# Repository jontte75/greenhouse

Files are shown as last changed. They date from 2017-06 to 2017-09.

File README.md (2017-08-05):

# Greenhouse Project #

This project contains source and fritzing of a project to automate a small greenhouse. For now, the soil-moisture probe is not "stable" enough, so automatic watering is not yet implemented. The current version does not contain a web-server, but sends data to thingspeak instead.

### Greenhouse repository ###
* source code for arduino microcontroller (first versions for pro mini, and later for mega)
* source code for one chip pic's, like Omega2 
* simplified fritzing picture of project.

### How do I get set up? ###
No special set-ups needed. Connect necessary devices and sensors to a arduino (project uses now Mega 2560 clone, but any other should work just fine, but be aware of memory requirements)

A simplified fritzing pic about the project:
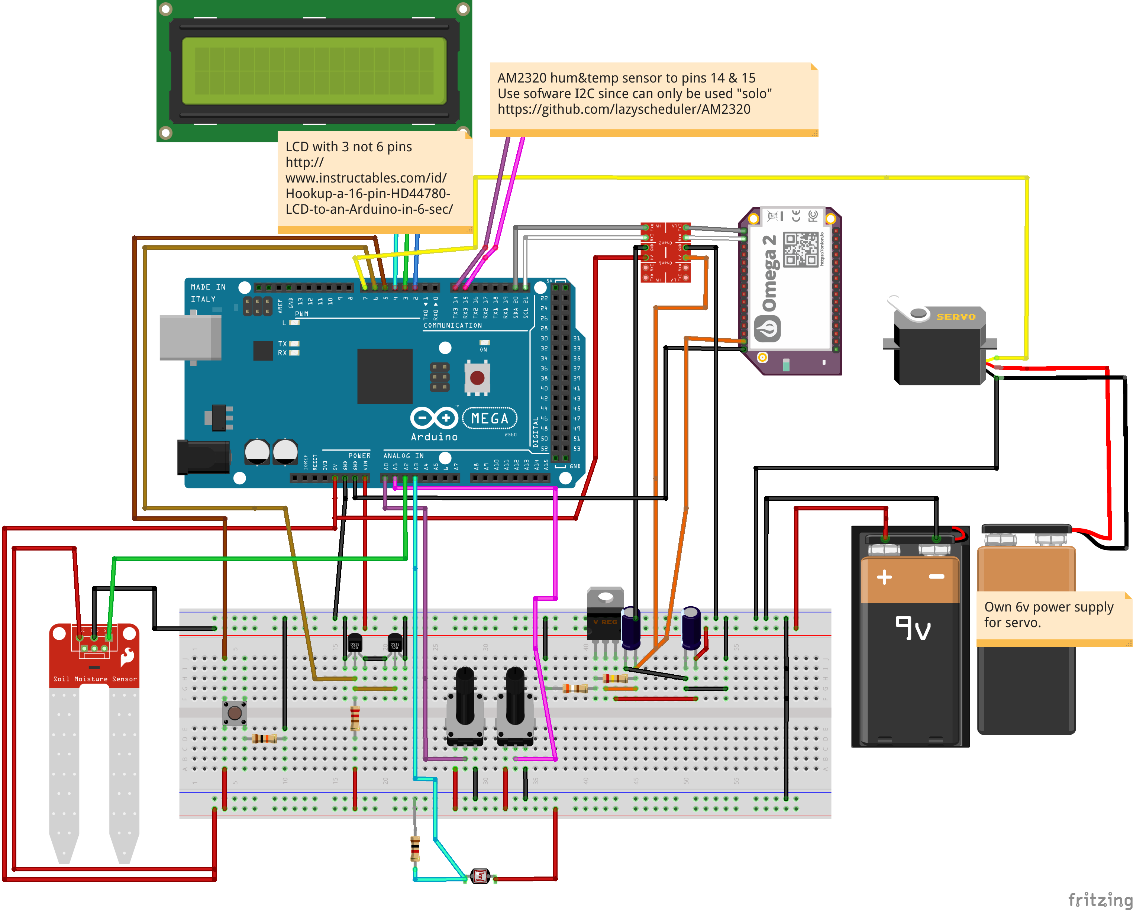
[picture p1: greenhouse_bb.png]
Project Frizing


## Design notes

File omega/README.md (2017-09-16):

# Omega2

This directory contains Omega2 related scripts and other source codes.

The Omega2 will be used as a minimal server for the Arduino, so that 
communications to outside world wil be done using Omega2 instead of Esp8266.
This is an attempt to tackle memory issues and instablility of the Arduino 
(But mostly an attempt to learn something new).

## Python

This directory contains different python scripts.

## i2ctest

This directory contains different i2c related test scripts and other code. 
Look file history, since these are just testing material, so...

## cpp

This directory contains processes made with C++

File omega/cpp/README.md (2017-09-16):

# Omega2 & CPP

This directory contains Omega2 related C/C++ code for different tasks.

## i2c
This folder contains process for communicating with Arduino using i2c. It also sends recieved data to ThingSpeak.

### i2ccom.*
This handles i2c communication with Arduino.

### i2cdata.*
This is used to validate and store data recieved from Arduino.

### tsclient.*
This is used to send data to ThingSpeak

### main.cpp
Main module. Starts two threads. One thread communicates with arduino and the other sends the data to ThingSoeak when all data has been recieved.

### Compilation
One need proper cros-compilation tool-chain (for omega2), or easiest way is to use dockerised compilation environment, like jlcs/omega2-docker-built.

```bash
$CXX $CFLAGS -std=gnu++11 $LDFLAGS -loniondebug -lonioni2c main.cpp i2cdata.cpp i2ccom.cpp tsclient.cpp -o i2ctest
```
Where:

```bash
LDFLAGS=-L/lede/staging_dir/target-mipsel_24kc_musl/usr/lib -L/home/omega/workspace/i2c-exp-driver/lib

CFLAGS=-I/lede/staging_dir/target-mipsel_24kc_musl/usr/include -I/home/omega/workspace/i2c-exp-driver/include

CXX=/lede/staging_dir/toolchain-mipsel_24kc_gcc-5.4.0_musl/bin/mipsel-openwrt-linux-g++
```

Or use the Makefile. Edit the correct paths to libraries and compiler.

### Usage
Start process by hand, or preferably make it to start automatically when Omega boots.

```bash
root@Omega-9D23:~# cat /etc/rc.local 
# Put your custom commands here that should be executed once
# the system init finished. By default this file does nothing.

./root/i2ctest YOURTHINGSPEAKWRITEKEY &

exit 0
root@Omega-9D23:~# 

```

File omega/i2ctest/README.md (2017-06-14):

# i2ctest

This directory contains different i2c related test scripts, which will and have been used to prototype interface bbetween Omega2 and Arduino (Mega 2560).

## i2ctest.ino
This is the arduino code for testing i2c. It will communicate with ***i2c.py*** running on Omega2. No extra pullups used, relies on builtins in Arduino. Bi-directional Logic level  shifter is required because Arduino works in 5v and Omega2 in 3.3v.
<pre>
Arduino                              LLS                           Omega2
*******                              ***                           ******
                                     _____
SCL<-------------------------------->|   |<------------------------->SCL
SDA<-------------------------------->|   |<------------------------->SDA
                                     -----           
</pre>
Arduino will work in slave mode, so that Omega2 will ask for data or toggle a led (nr 13)

## i2c.py
This will work as a master and requests data from arduino.
First a hello and then some data (with simple checksum)

<pre>
In Omega2 required packages:
opkg install python-light pyOnionI2C 
opkg install python-codecs
</pre>

run ***i2c.py -h***  for help

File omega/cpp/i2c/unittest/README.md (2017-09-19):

# Unittests

This directory contains unittests (as the name suggests)
No crosscompilation, if not intended to run in target environment

You need to set couple of environment varaiables:
__GTESTINC__ the path to google test include directory
__ONIONI2CINC__ the path to include directory of omegas i2c-exp-driver

Work In Progress

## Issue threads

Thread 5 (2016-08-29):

Two-way communication

jontte75, 2016-08-29:
It should be possible to check state of window, and the forcedly open or close the window.
Same for watering and lamp.
- ESP might not be stable enough.
- We are on limits of Arduino pro mini
  - add more arduinos or replace by Mega
  - check if raspberry-pi or (coming) Omega2 could be used as companion.

jontte75, 2017-08-04:
Ongoing i2c project handles this partially.
One chip pc handles sending of data to cloud, by requesting values from arduino (Mega)

jontte75, 2018-10-04:
Future development, coming projects will take care of this

Closed 2018-10-04.

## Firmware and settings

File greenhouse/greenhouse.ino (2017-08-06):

/**
   Greenhouse-project
   - monitor temperature and humidity. If temperature rises too high (or humidity), then open the window
   - monitor also soil humidity
   - note the "state" is just state of display

   Help and ideas have been gathered from many sources, thanx to all!
   E.g from:
   http://www.instructables.com/id/Hookup-a-16-pin-HD44780-LCD-to-an-Arduino-in-6-sec/
   http://www.instructables.com/id/Temperature-with-DS18B20/
   https://learn.adafruit.com/photocells/using-a-photocell
   http://www.instructables.com/id/Connecting-AM2320-With-Arduino/
   http://allaboutee.com/2015/01/02/esp8266-arduino-led-control-from-webpage/
   https://github.com/lazyscheduler/AM2320
   and many other resources
*/

#include <LiquidCrystal595.h>
#include <Servo.h>
#include <OneWire.h>
#include <DallasTemperature.h>
#include <avr/pgmspace.h>
#include <Wire.h>
#include <AM2320.h>
#include "./greenhouse_log.h"

//state handling
#define STATE_INITIAL   0
#define STATE_WORKING   1
#define STATE_SETUP     2
byte state = STATE_INITIAL;

//analog pin assignments
#define TEMP_POT_PIN     A0
#define HUM_POT_PIN      A1
#define MOIST_SENS1_PIN  A2
#define LIGHTSENS_PIN    A5

//digital pin assignments
#define LCDPIN1          2
#define LCDPIN2          3
#define LCDPIN3          4
#define BTNPIN           5
#define DALLAS_ONE_WIRE  6
#define SERVOPIN         7
#define I2C_INDICATORLED 13
#define AM_SCL           14
#define AM_SDA           15


//I2C related
#define I2C_SLAVEID           0x10
#define I2C_CMD_HELLO         0x00
#define I2C_CMD_GET_DATA_SET1 0x01
#define I2C_CMD_GET_DATA_SET2 0x02
#define I2C_CMD_TOGGLE_WATER  0x0A
#define I2C_CMD_TOGGLE_LIGHT  0x0B
#define I2C_INITIAL_VAL       0xFF
#define I2C_BUFFER_SZ         0x06
#define I2C_BUFFER2_SZ        0x06

// The baud rate of the serial interface
#define SERIAL_BAUD  9600

// How often should we read sensors
#define READINTERVAL (10*1000)

//global variables sent outside
volatile float   tempSensorValue;
volatile float   humSensorValue;
boolean hatchOpen = false;
volatile uint8_t moisture = 100;
volatile float  tempCase = 0; //temp inside the gadget
volatile float  tempOutside = 0; //temp outside the greenhouse
volatile uint16_t lightSensValue = 0;

//global internally used
int8_t  maxC = 125, minC = -125;
uint8_t tempLimitPotValue = 0; //these values vary, use when set
uint8_t humLimitPotValue = 0;  //these values vary, use when set
uint8_t buttonState = LOW;
uint8_t alertLevel  = 30; //alert level for temp stored from tempLimitPotValue
uint8_t humLevel    = 80; //alert level for humidy stored from humLimitPotValue
uint8_t updateValuesCntr = 0;
volatile unsigned long lastTimeReadValues = 0;

// Setup a oneWire instance to communicate with any OneWire devices
OneWire oneWire(DALLAS_ONE_WIRE);

// Pass the oneWire reference to Dallas Temperature.
DallasTemperature sensors(&oneWire);

//initialize the AM2320 library
//Note! Need to use library that supports SoftWire
//otherwise collides with I2C between Omega and Arduino 
//This library also supports multiple AM2320 sensors..
//https://github.com/lazyscheduler/AM2320 
AM2320 th(AM_SCL, AM_SDA);

// Initialize the LCD library with the interface pins
LiquidCrystal595 lcd(LCDPIN1, LCDPIN2, LCDPIN3);
Servo servo1; // Create a servo object

// Some global variables
volatile byte command = I2C_INITIAL_VAL;
volatile uint8_t i2c_ongoing = 0;
volatile static float buffer[I2C_BUFFER_SZ]={I2C_INITIAL_VAL};
volatile static float buffer2[I2C_BUFFER2_SZ]={I2C_INITIAL_VAL};
/*---------------------setup and main loop---------------------*/

void setup() {
  tempSensorValue = humSensorValue = 0;
  SERIAL_BEGIN(SERIAL_BAUD);
  delay(500);
  LOG_DEBUGLN("\nStarting up...");
  lcd.begin(16, 2); // Set the display to 16 columns and 2 rows
  lcd.clear();
  lcd.setCursor(0, 0);
  lcd.print("Set up I2C.");
  Wire.begin(I2C_SLAVEID);
  Wire.onRequest(requestEvent);
  Wire.onReceive(receiveEvent);
  delay(2000);
  lcd.clear();
  lcd.setCursor(0, 0);
  lcd.print("Set up servo.");
  turnServo(180);
  
  analogReference(DEFAULT);
  pinMode(BTNPIN, INPUT);

  pinMode(MOIST_SENS1_PIN, INPUT);
  pinMode(I2C_INDICATORLED, OUTPUT);

  // Initialize the library for temperature sensors
  delay(300);
  lcd.clear();
  lcd.setCursor(0, 0);
  lcd.print("Set up sensors.");
  sensors.begin();
  delay(100);

  //read values, especially potentiometer values, incase of restart
  readValues(0,true);
  readConfigSensors();
  alertLevel = tempLimitPotValue;
  humLevel = humLimitPotValue;

  state = STATE_INITIAL;

  // Timer0 is already used for millis() - we'll just interrupt somewhere
  // in the middle and call the "Compare A" function below
  OCR0A = 0xAF;
  TIMSK0 |= _BV(OCIE0A);
  delay(300);
  lcd.clear();
  lcd.setCursor(0, 0);
  lcd.print("Setups done.");
  delay(3000);
}

SIGNAL(TIMER0_COMPA_vect)
{
  unsigned long currentMillis = millis();
  readValues(currentMillis, false);
}

//Request Event callback function, will be called when master reads from I2C bus
void requestEvent() {
  switch (command){
    case I2C_CMD_HELLO:
      Wire.write("Hello!");
      break;
    case I2C_CMD_GET_DATA_SET1:
      Wire.write((byte*)&buffer[0], sizeof(buffer));
      break;
    case I2C_CMD_GET_DATA_SET2:
      Wire.write((byte*)&buffer2[0], sizeof(buffer2));
      break;
    default:
       Wire.write(I2C_INITIAL_VAL);
  }
  i2c_ongoing = 0;
  //digitalWrite(I2C_INDICATORLED, !digitalRead(I2C_INDICATORLED));
}

// Receive Event callback, called when master writes data to I2C bus
void receiveEvent(int bytes)
{
  //digitalWrite(I2C_INDICATORLED, !digitalRead(I2C_INDICATORLED));
  (void)Wire.read();//address
  byte cmd = Wire.read();
  switch (cmd) {
    case I2C_CMD_HELLO:
      command = cmd;
      break;
    case I2C_CMD_GET_DATA_SET1:
      buffer[0] = tempSensorValue;
      buffer[1] = humSensorValue;
      buffer[2] = tempCase;
      buffer[3] = tempOutside;
      buffer[4] = lightSensValue;
      buffer[I2C_BUFFER_SZ-1] = (float)((buffer[0]+buffer[1]+buffer[2]+buffer[3]+buffer[4])/5);
      command = cmd;
      break;
    case I2C_CMD_GET_DATA_SET2:
      buffer2[0] = moisture;
      buffer2[1] = hatchOpen;
      buffer2[2] = 0;
      buffer2[3] = 0;
      buffer2[4] = 0;   
      buffer2[I2C_BUFFER2_SZ-1] = (float)((buffer2[0]+buffer2[1]+buffer2[2]+buffer2[3]+buffer2[4])/5);
      command = cmd;
      break;
    case I2C_CMD_TOGGLE_WATER:
    case I2C_CMD_TOGGLE_LIGHT:
      command = I2C_INITIAL_VAL;
      break;
    default:
      LOG_ERROR("Unexpected command value ");
      LOG_ERRORLN(cmd);
  }
  i2c_ongoing = 1;
}

//The main loop
void loop()
{
  buttonState = digitalRead(BTNPIN); // Check for button press
  lcd.setCursor(0, 0); // Set cursor to home position
  handleState();
  delay(100);
}

void readConfigSensors()
{
  delay(10);
  readTemperatureLimit();
  LOG_DEBUG("tp:");
  LOG_DEBUGLN(tempLimitPotValue);
  delay(10);
  readHumidityLimit();
  LOG_DEBUG("hp:");
  LOG_DEBUGLN(humLimitPotValue);

}

void handleState()
{
  if (buttonState == HIGH) {
    LOG_DEBUG("button pressed, state is");
    LOG_DEBUGLN(state);
    if (state == STATE_INITIAL || state == STATE_WORKING) {
      state = STATE_SETUP;
      lcd.setLED2Pin(LOW);
      lcd.setLED1Pin(LOW);
      lcd.print("");
    }
    else {
      lcd.setLED2Pin(HIGH);
      lcd.setLED1Pin(HIGH);
      lcd.print("");
      state = STATE_WORKING;
      alertLevel = tempLimitPotValue;
      humLevel = humLimitPotValue;
    }
  }

  if (state == STATE_SETUP) {
    stateSetup();
  }else{
    stateWorking();
  }
}

bool read_from_am2320() {
  switch (th.Read()) {
    case 2:
      LOG_ERRORLN("CRC failed");
      return false;
      break;
    case 1:
      LOG_ERRORLN("Sensor offline");
      return false;
      break;
    default:
      break;
  }
  return true;
}

void readSoilMoisture() {
  uint16_t tempAnalogValue = 0;
  tempAnalogValue = analogRead(MOIST_SENS1_PIN);
  delay(10);
  tempAnalogValue = analogRead(MOIST_SENS1_PIN);
  LOG_DEBUGLN(tempAnalogValue);
  moisture = uint8_t(100 * (1 - ((double)(tempAnalogValue) / 1023)));
}

void readTemperatureLimit() {
  uint16_t tempAnalogReadVal = 0;
  //read twice because of reading issues (sometimes)
  tempAnalogReadVal = analogRead(TEMP_POT_PIN); // Read the pot value
  delay(10);
  tempAnalogReadVal = analogRead(TEMP_POT_PIN); // Read the pot value
  tempLimitPotValue = map(tempAnalogReadVal, 0, 1023, 10, 100); // Map the values from 10 to 100 degrees
}

void readHumidityLimit() {
  uint16_t tempAnalogReadVal = 0; 
  //read twice because of reading issues (sometimes)
  tempAnalogReadVal = analogRead(HUM_POT_PIN); // Read the pot value
  delay(10);
  tempAnalogReadVal = analogRead(HUM_POT_PIN); // Read the pot value
  humLimitPotValue = map(tempAnalogReadVal, 0, 1023, 20, 100); // Map the values from 20 to 100%
}

void readValues(unsigned long currentMillis, bool forced)
{
  if (state == STATE_SETUP || (((currentMillis-lastTimeReadValues) < READINTERVAL) && !forced)){
    return;
  }
  LOG_DEBUGLN("Reading values...");
  lastTimeReadValues = millis();

  //get dallas values
  sensors.requestTemperatures();

  if (true == read_from_am2320()) {
    if (isnan(th.h) || isnan(th.t)) {
      LOG_ERRORLN("Invalid values from AM2320");
    } else {
      humSensorValue = th.h;
      tempSensorValue = th.t;
    }
  } else {
    LOG_ERROR("Failed to get values from AM2320");
  }
  LOG_DEBUG("HUM: ");
  LOG_DEBUGLN(humSensorValue);
  LOG_DEBUG("TEMP: ");
  LOG_DEBUGLN(tempSensorValue);

  readSoilMoisture();
  LOG_DEBUG("SOIL: ");
  LOG_DEBUGLN(moisture);
  delay(10);

  float tempCaseTemp = sensors.getTempCByIndex(0);
  float tempOutsTemp = sensors.getTempCByIndex(1);
  if (isnan(tempCaseTemp) || isnan(tempOutsTemp)) {
    LOG_DEBUGLN("Could not get dallas temperature");
  } else {
    tempCase = tempCaseTemp;
    tempOutside = tempOutsTemp;
  }
  LOG_DEBUG("to:");
  LOG_DEBUGLN(tempOutsTemp);
  LOG_DEBUG("tc:");
  LOG_DEBUGLN(tempCaseTemp);

  lightSensValue = analogRead(LIGHTSENS_PIN);
  LOG_DEBUG("LDR:");
  LOG_DEBUGLN(lightSensValue);
}

void turnServo(uint16_t degree)
{
  servo1.attach(SERVOPIN); // Attaches the servo on pin 14 to the servo1 object
  servo1.write(degree);  // Put servo1 at home position
  delay(3000);
  servo1.detach();  //detach not to disturb SoftwareSerial
}

void stateWorking()
{
  writeTempAndHumToLcd();

  if (!hatchOpen && (tempSensorValue >= alertLevel || ( humSensorValue >= humLevel && tempSensorValue >= 20))) {
    LOG_DEBUG2("Alert! over ");
    LOG_DEBUG2(alertLevel);
    LOG_DEBUG2("degrees, open hatch\n");
    turnServo(90);
    hatchOpen = true;
  }
  if (hatchOpen && ((tempSensorValue <= (alertLevel - 2) && humSensorValue <= (humLevel - 2)) || tempSensorValue <= 20)) {
    LOG_DEBUG2("Alert! less than ");
    LOG_DEBUG2(alertLevel);
    LOG_DEBUG2("(");
    LOG_DEBUG2(tempSensorValue);
    LOG_DEBUG2(") degrees, close hatch\n");
    turnServo(180);
    hatchOpen = false;
  }
}

void writeTempAndHumToLcd() {
  char float_str[10] = {0};
  lcd.setCursor(0, 0);
  dtostrf(tempSensorValue, 4, 1, float_str);
  lcd.print(float_str);
  lcd.write(B11011111); // Degree symbol
  lcd.print("C ");
  memset(&float_str, 0, sizeof(float_str));
  dtostrf(humSensorValue, 3, 1, float_str);
  lcd.print("H=");
  lcd.print(float_str);
  lcd.print("\%");

  if ((int)tempSensorValue > maxC ||
      ((int)tempSensorValue < maxC && maxC == 125 && (int)tempSensorValue != 0 )) {
    maxC = (int)tempSensorValue;
  }
  if ((int)tempSensorValue < minC && minC != -125 ||
      ((int)tempSensorValue > minC && minC == -125 && (int)tempSensorValue != 0 )) {
    minC = (int)tempSensorValue;
  }
  lcd.setCursor(0, 1);
  lcd.print("Hi=");
  lcd.print(maxC);
  lcd.write(B11011111);
  lcd.print("C Lo=");
  lcd.print(minC);
  lcd.write(B11011111);
  lcd.print("C ");
}

void displaySetup() {
  readConfigSensors();
  lcd.clear();
  lcd.setCursor(0, 0);
  lcd.print("T:");
  lcd.print(tempLimitPotValue);
  lcd.print("(");
  lcd.print(alertLevel);
  lcd.print(")          ");
  lcd.setCursor(0, 1);
  lcd.print("H:");
  lcd.print(humLimitPotValue);
  lcd.print("(");
  lcd.print(humLevel);
  lcd.print(")        ");

}

void stateSetup()
{
  displaySetup();
}

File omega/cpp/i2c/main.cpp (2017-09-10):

/*
 * =====================================================================================
 *
 *       Filename:  main.cpp
 *
 *    Description:  
 *
 *        Version:  1.0
 *        Created:  20.08.2017 20.52.20
 *       Revision:  none
 *       Compiler:  g++
 *
 *         Author:  Joni Korhonen 
 *   Organization:  
 *
 * =====================================================================================
 */
#include <cstdint>
#include <cstring>
#include <cstddef>
#include <iostream>
#include <string>
#include <sstream>
#include <fstream>
#include <cmath>
#include <thread>
#include <chrono>
#include <mutex>
#include <queue>
#include <condition_variable>
#include "onion-i2c.h"
#include "i2cdata.h"
#include "i2ccom.h"
#include "tsclient.h"

std::mutex mtex;
std::condition_variable cv;
std::queue<i2cd::I2cData> dataQueue;

bool success=false;

void i2cComThr(int retries) {
    i2cc::I2cCom conn;
    //connect to arduino (check i2c with simple hello)
    conn.connect();
    
    while(true){
        uint8_t dsind=1;
        for (int i=1;i<i2cc::I2cCom::I2C_CMD_MAX;i++){
            std::lock_guard<std::mutex> lk(mtex);
            i2cd::I2cData dataSet(dsind);
            success = false;
            int retryCnt = retries;
            while(retryCnt){
                conn.storeDataFromI2c(i);
                if(!dataSet.setData(conn.getData(), i2cc::I2cCom::I2C_DEF_BYTES))
                {
                    std::cout << "Ohno invalid data from i2c" << std::endl;
                    retryCnt--;
                    success = false;
                    std::this_thread::sleep_for(std::chrono::seconds(10));
                    continue;
                }
                // std::cout << "Data recieved:" << set1 <<std::endl;
                dataQueue.push(dataSet);
                success = true;
                break;
            }
            if(!success){
                break;
            }
            dsind+=5;
        }
        if (success){
            cv.notify_all();
            success = false;
            std::this_thread::sleep_for(std::chrono::seconds(300));        
        }else{
            //something went wrong, we could not get all data from Arduino
            std::lock_guard<std::mutex> lk(mtex);
            while(!dataQueue.empty()){
                dataQueue.pop();    
            }
            //wait for a while before requesting data again, but not as long as the TS interval is
            std::this_thread::sleep_for(std::chrono::seconds(60));        
        }

    }
}

void thingSpeakThr(std::string apikey) {
    tsc::tsClient tsc(apikey);
	while (true) {
        //wait requires unique_lock
        std::unique_lock<std::mutex> lk(mtex);
        cv.wait(lk, []{return success || !dataQueue.empty(); });
        std::ostringstream data;
        while (!dataQueue.empty()) {
                std::cout<<"--------------------"<<std::endl;
                data << dataQueue.front();
                std::cout<<"--------------------"<<std::endl;
                dataQueue.pop();
        }        
        data << "\r\n";
        tsc.conn("184.106.153.149", 80);
        tsc.send_data(std::string(data.str()));
        std::cout << "status:" << tsc.receive(256);
	}
}

int main(int argc , char *argv[])
{
    if (argc < 2 || argc > 2){
        std::cerr << "Usage: " << argv[0] << "THINGSPEAKWRITEAPIKEY" << std::endl;
        return 1;
    }
    
    std::string apikey(argv[1]);
	std::thread t1(&i2cComThr, 5);
	std::thread t2(&thingSpeakThr, apikey);

    t1.join();
    t2.join();

    std::cout<<"Main done!"<<std::endl;
 
    return 0;
}

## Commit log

2015-05-28 Initial commit
    Initial commit of greenhouse project
    Contains arduino code and fritzing
    [greenhouse.fzz]
2015-10-15 small fixes and fine tunings
    also to reduse memory foot print, if too much memory used
    serial communication with esp will fail!
    [greenhouse.ino]
2016-06-02 Almost completely rewritten
    Changed temp+hum sensor from dht11 to AM2320.
    Changed to send datat to thingspeak instead of
    hosting own web server. Introduced debug-logs,
    so that serial is not used at all if DEBUG is less
    than 1 --> saves a lot of memory.
2016-06-06 New features and WA for wifi problems
    Added new sensors, two temperature (DS) for measuring temperature
    inside the box and one for outside temperature.
    Added also measuring of light conditions.
    To tackle weird "jamming" issues related to esp-05, added forced
    restart of esp, every 12h. Let's see if that helps (has now been
    working for over 24h).
    [greenhouse.ino]
2016-06-08 updated fizz and added png
    [greenhouse.fzz]
2016-06-23 Small editorial changes
    Removed some wrong and/or unnecessary comments
    [greenhouse.ino]
2016-07-04 ISSUE #2
    Separate updating of ThingSpeak (and handling of esp8266) from main
    file (ino), to make code more clear.
    Changed handling of ThingSpeak and ESP8266 so that a new module (class)
    is added for handling updating of ThingSpeak. Some more cleanup needed,
    but code has now run successfully in "live" tesing in greenhouse for
    24h.
    [greenhouse.ino, updateThingspeak.cpp]
2016-08-01 ISSUE #2
    clean-up double declarations...
    [updateThingspeak.cpp]
2017-02-10 NEW: omega2
    Added a test sketch and python file to test and
    tune the i2c communication between arduino and omega2.
    This will be used as base for communication in the real
    project.
2017-02-10 NEW: omega2
    Added .gitignore
    Added vscode project file for i2ctest
2017-02-12 NEW: omega2
    Modified test script and sketch and tuned reliability.
    Python script starts automatically without need for user input.
    The arduino sketch modified for readability and some fine tunings.
2017-02-17 i2ctest
    Added cmd line arguments for user to define loop from
    0-100, where 0 means infinite loop(request data from Arduino/i2c)
    Changed test also to use floating numbers, whic will be used in
    real product also. Since only 32 bit can fit, have to start
    balancing...
2017-02-17 i2ctest
    small fixes to print statements, now containing parenthesis for
    easier python3 conversion if needed.
2017-06-13 i2ctest
    small changes and fine tunings
2017-06-14 i2ctest
    updated README.md
2017-06-14 i2ctest
    Fixed md syntax in README.md file
2017-06-19 I2C changes
    first i2c related changes to real code.
    debugging is set to 1 to enable Serial, since that seems to be
    required for I2C/Wire library to work.
    Since only 32 fits in i2c message, we will have to split the message
    in two...
2017-06-21 I2C changes
    Some fine tuning. Added new buffer for data set 2 (could also use
    the one fore set 1, but for now using separate to help debugging)
    Added also useage of timer. Now sensors are read every 10s, so main
    loop remains cleaner (state change button should not now be disturbed
    about delays in main loop)
2017-08-04 I2C changes and bugfixes
    Fixed issue with "sensor offline" of AM2320, which was
    caused because of collision with Wire configuration for
    I2C between Omega and Arduino. Changed to different AM2320
    library, which uses softWire and can be defined to used
    different pins for Wire communication.
    Changed also python test script to request for data set 2
    (since only limted amount fits in one request). The test script
    is now tested with real code, not the thest one...
    [greenhouse.ino]
2017-08-06 Bugfixes
    Fixed issue with setup, not showing changing values on display.
    Changed code so that cfg related values are read when in setup
    or init state.
    [greenhouse.ino]
2017-09-03 I2C CPP
    Change of plans...
    Decieded to make the I2C communications with C++ instead
    This is the first test version, compiled like this:
    $CXX $CFLAGS -std=gnu++11 $LDFLAGS -loniondebug -lonioni2c main.cpp
    i2cdata.cpp i2ccom.cpp -o i2ctest
    where:
    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
2017-09-07 I2C CPP POC
    Modified so that i2c communication is done in one thread (forever-loop)
    An other thread will handle sending to thingSpeak, when ever i2c-thread
    inform that it has data...classic producer consumer thing...
2017-09-10 NEW: I2C CPP PoC
    Changed code to send data to thingspeak (fixed ip for now)
    Started using namespaces (not needed for now but..)
    Thingspeak key must be given as a parameter to the process
    [i2ccom.cpp, i2cdata.cpp, main.cpp]
2017-09-10 FIX: I2C CPP PoC
    moved i2c related code to own directory.
    Added more information to README.md
    [i2ccom.cpp, i2cdata.cpp, main.cpp]
2017-09-15 FIX: gitignore
    Added i2ctest to ignored files...
2017-09-16 FIX: warnings and missing Makefile
    Fixed some warnings, and added a Makefile
    [i2ccom.cpp, i2cdata.cpp]
2017-09-17 NEW: I2C and Omega2
    Modified the fritzing to be more like the current "design"
    It is just a principal figure...
    [greenhouse.fzz]
2017-09-17 FIX: bugfix in fritzing
    couple of wires were wrong
    [greenhouse.fzz]
2017-09-19 NEW: Unittests
    Added simple unittest (google UT framework)
